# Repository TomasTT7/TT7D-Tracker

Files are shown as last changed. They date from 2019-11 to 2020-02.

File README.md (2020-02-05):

# TT7D-Tracker
This is the main repository for TT7D, a simple APRS / RTTY high altitude balloon tracker. It includes the board and schematic design files for Eagle, and the current firmware.

### Components:
- microcontroller: ATmega328P-AU
- GNSS module: u-blox MAX-M7 / MAX-M8 / GM10
- transmitter: Si4060 / Si4063 / Si4460 / Si4463
- TCXO: IT3205CE
- boost regulator: MCP1640B
- power supply: AAA battery / 2x solar cell
- GNSS antenna: JTI 1575AT43A0040 / wire

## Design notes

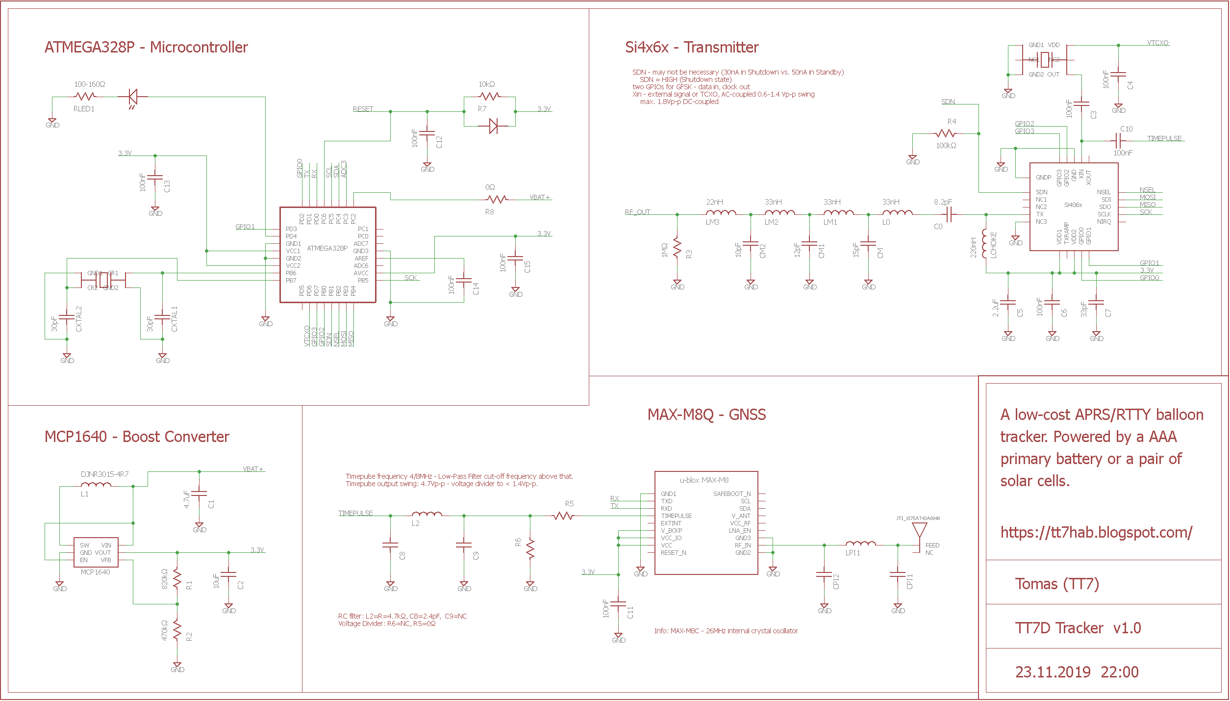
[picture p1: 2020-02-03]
Hardware/TT7D v1.0 schematic.png

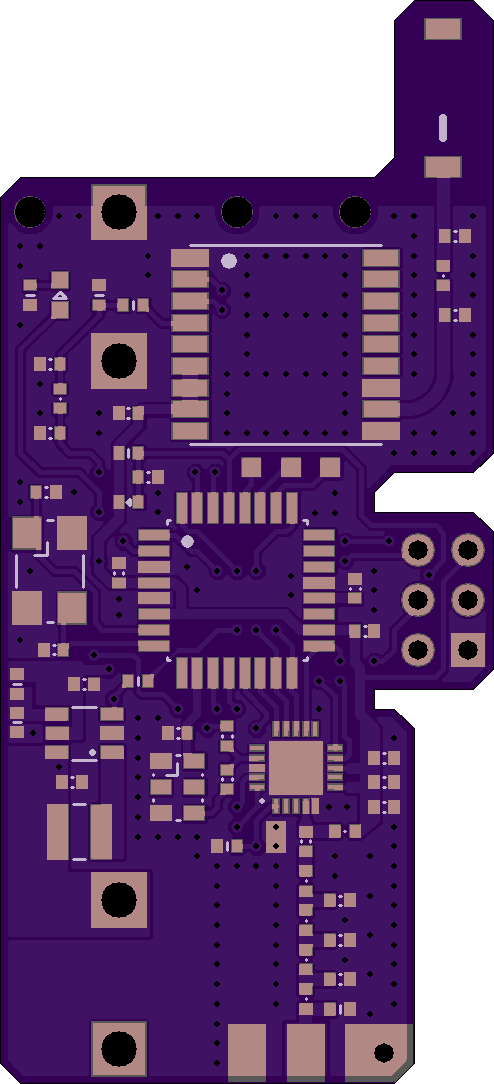
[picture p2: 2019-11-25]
Hardware/TT7D v1.0 top.png

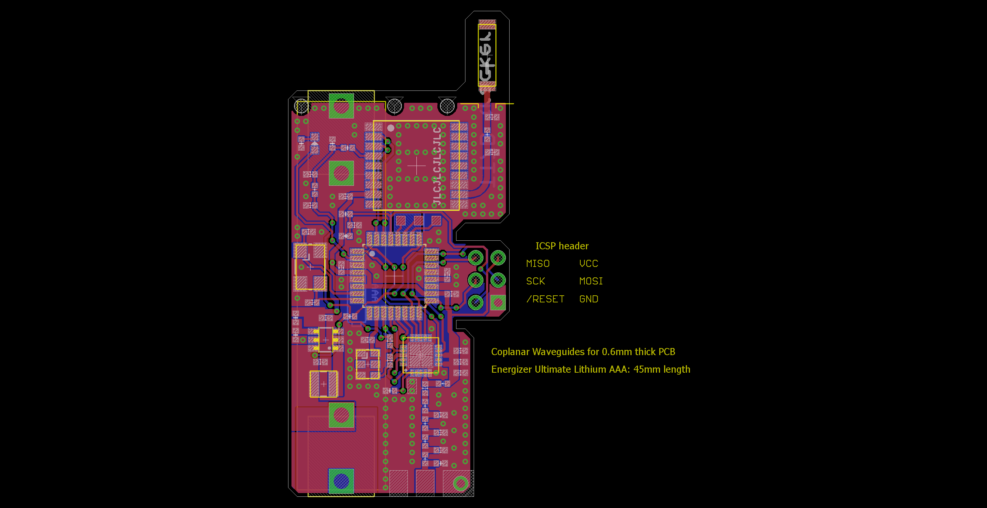
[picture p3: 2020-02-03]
Hardware/TT7D v1.0 board.png

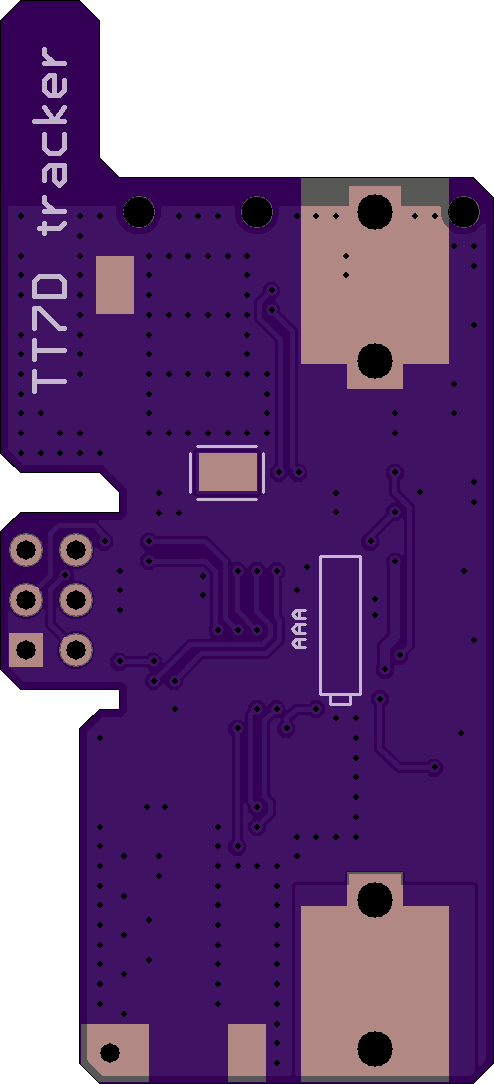
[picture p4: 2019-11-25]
Hardware/TT7D v1.0 bottom.png

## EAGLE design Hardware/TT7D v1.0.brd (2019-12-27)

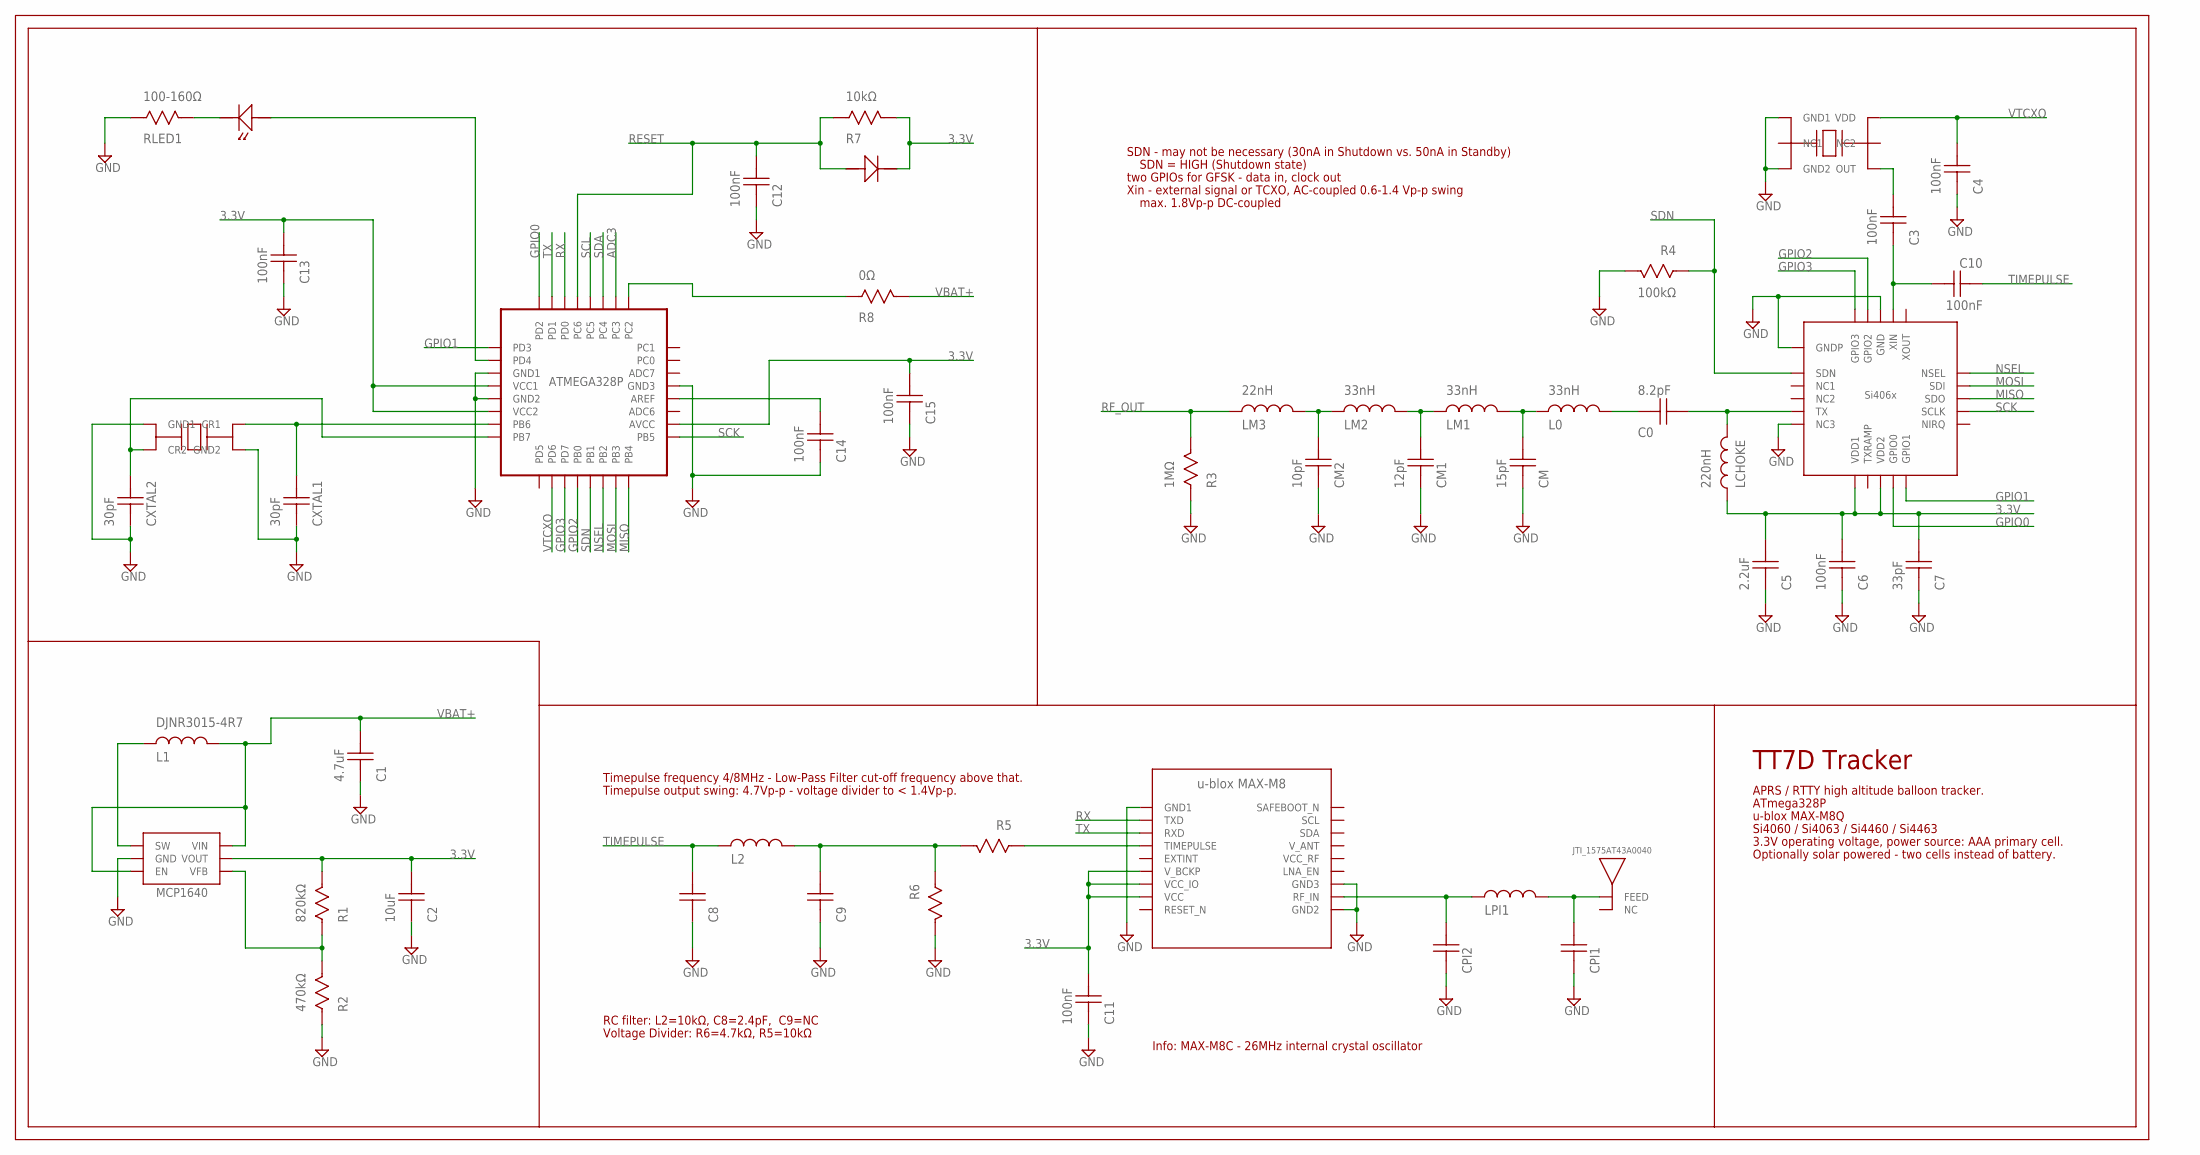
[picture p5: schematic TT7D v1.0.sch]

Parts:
ANT1: JTI_1575AT43A0040
C0: 8.2pF; CAP0402
C1: 4.7uF; CAP0402
C2: 10uF; CAP0402
C3, C4, C6, C10, C11, C12, C13, C14, C15: 100nF; CAP0402
C5: 2.2uF; CAP0402
C7: 33pF; CAP0402
C8, C9: CAP0402
CM: 15pF; CAP0402
CM1: 12pF; CAP0402
CM2: 10pF; CAP0402
CPI1, CPI2: CAP0402
CXTAL1, CXTAL2: 30pF; CAP0402
D1: DIODE0402
L0: 33nH; IND0402
L1: DJNR3015-4R7; DJNR3015
L2: IND0402
LCHOKE: 220nH; IND0402
LED1: LED0603
LM1, LM2: 33nH; IND0402
LM3: 22nH; IND0402
LPI1: IND0402
R1: 820kΩ; RES0402
R2: 470kΩ; RES0402
R3: 1MΩ; RES0402
R4: 100kΩ; RES0402
R5, R6: RES0402
R7: 10kΩ; RES0402
R8: 0Ω; RES0402
RLED1: 100-160Ω; RES0402
U1: ATMEGA328P-AU
U2: UBLOX_MAX-7C
U3: SI406X
U4: IT3205CE_TCXO_6P
U5: MCP1640
XTAL1: LFXTAL055663

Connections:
3.3V: C2.P$2, C5.P$2, C6.P$2, C7.P$2, C11.P$2, C13.P$2, C15.P$2, D1.CATHODE, LCHOKE.P$1, R1.P$2, R7.P$2, U1.AVCC, U1.VCC1, U1.VCC2, U2.VCC, U2.VCC_IO, U2.V_BCKP, U3.VDD1, U3.VDD2, U5.VOUT
ADC3: U1.PC3
GND: C1.P$1, C2.P$1, C4.P$1, C5.P$1, C6.P$1, C7.P$1, C8.P$1, C9.P$1, C11.P$1, C12.P$1, C13.P$1, C14.P$1, C15.P$1, CM.P$1, CM1.P$1, CM2.P$1, CPI1.P$1, CPI2.P$1, CXTAL1.P$1, CXTAL2.P$1, R2.P$1, R3.P$1, R4.P$2, R6.P$2, RLED1.P$1, U1.GND1, U1.GND2, U1.GND3, U2.GND1, U2.GND2, U2.GND3, U3.GND, U3.GNDP, U3.NC3, U4.GND1, U4.GND2, U5.GND, XTAL1.GND1, XTAL1.GND2
GPIO0: U1.PD2, U3.GPIO0
GPIO1: U1.PD3, U3.GPIO1
GPIO2: U1.PB0, U3.GPIO2
GPIO3: U1.PD7, U3.GPIO3
MISO: U1.PB4, U3.SDO
MOSI: U1.PB3, U3.SDI
unnamed: CXTAL2.P$2, U1.PB7, XTAL1.CRYSTAL2 (CR2)
unnamed: CXTAL1.P$2, U1.PB6, XTAL1.CRYSTAL1 (CR1)
unnamed: LED1.CATHODE, RLED1.P$2
unnamed: CPI2.P$2, LPI1.P$1, U2.RF_IN
unnamed: L1.P1, U5.SW
unnamed: CM.P$2, L0.P$1, LM1.P$2
unnamed: CM1.P$2, LM1.P$1, LM2.P$2
unnamed: R1.P$1, R2.P$2, U5.VFB
unnamed: CM2.P$2, LM2.P$1, LM3.P$2
unnamed: C0.P$1, L0.P$2
unnamed: C0.P$2, LCHOKE.P$2, U3.TX
unnamed: C14.P$2, U1.AREF
unnamed: C3.P$1, C10.P$2, U3.XIN
unnamed: C3.P$2, U4.OUT
unnamed: LED1.ANODE, U1.PD4
unnamed: R5.P$1, U2.TIMEPULSE
unnamed: C9.P$2, L2.P$2, R5.P$2, R6.P$1
unnamed: R8.P$1, U1.PC2
NSEL: U1.PB2, U3.NSEL
RESET: C12.P$2, D1.ANODE, R7.P$1, U1.PC6
RF_IN: ANT1.FEED, CPI1.P$2, LPI1.P$2
RF_OUT: LM3.P$1, R3.P$2
RX: U1.PD0, U2.TXD
SCK: U1.PB5, U3.SCLK
SCL: U1.PC5
SDA: U1.PC4
SDN: R4.P$1, U1.PB1, U3.SDN
TIMEPULSE: C8.P$2, C10.P$1, L2.P$1
TX: U1.PD1, U2.RXD
VBAT+: C1.P$2, L1.P2, R8.P$2, U5.EN, U5.VIN
VTCXO: C4.P$2, U1.PD6, U4.VDD

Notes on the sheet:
SDN - may not be necessary (30nA in Shutdown vs. 50nA in Standby)
SDN = HIGH (Shutdown state)
two GPIOs for GFSK - data in, clock out
Xin - external signal or TCXO, AC-coupled 0.6-1.4 Vp-p swing
max. 1.8Vp-p DC-coupled
Timepulse frequency 4/8MHz - Low-Pass Filter cut-off frequency above that.
Timepulse output swing: 4.7Vp-p - voltage divider to < 1.4Vp-p.
Info: MAX-M8C - 26MHz internal crystal oscillator
TT7D Tracker
APRS / RTTY high altitude balloon tracker.
ATmega328P
u-blox MAX-M8Q
Si4060 / Si4063 / Si4460 / Si4463
3.3V operating voltage, power source: AAA primary cell.
Optionally solar powered - two cells instead of battery.
RC filter: L2=10kΩ, C8=2.4pF, C9=NC
Voltage Divider: R6=4.7kΩ, R5=10kΩ

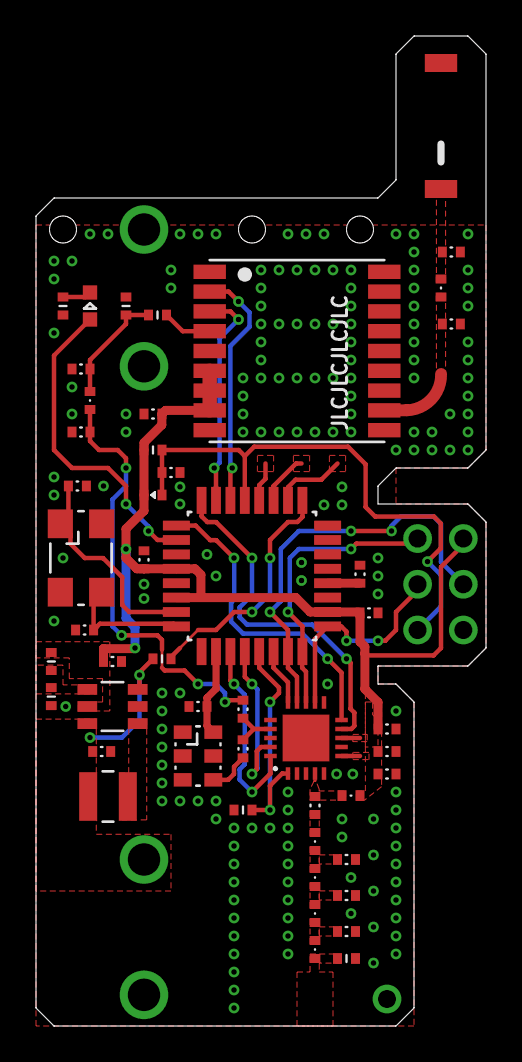
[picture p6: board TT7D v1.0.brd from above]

Board: 2 copper layers, 25.0 x 55.0 mm, 49 parts (0 on the bottom side), 37 nets.

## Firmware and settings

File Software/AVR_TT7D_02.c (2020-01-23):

/*
	Firmware for TT7D balloon tracker. Power saving low duty cycle version.
*/ 


// F_CPU defined in AVR/GNU C Compiler / Symbols


#include <avr/io.h>
#include <util/delay.h>
#include "AVR_ADC.h"
#include "AVR_APRS.h"
#include "AVR_GEOFENCE.h"
#include "AVR_RTTY.h"
#include "AVR_SERIAL.h"
#include "AVR_SI4X6X.h"
#include "AVR_SLEEP.h"
#include "AVR_SPI.h"
#include "AVR_TC.h"
#include "AVR_UART.h"
#include "AVR_UBLOX.h"
#include "AVR_WDT.h"


#define APRS																	// comment out to disable APRS
#define RTTY																	// comment out to disable RTTY

#define RTTY_FREQ		434300000												// [Hz] RTTY frequency

#define RTTY_CALL		"TT7D"
#define APRS_CALL		"OK7DMT"
#define APRS_SSID		15

#define RTTY_PWR		20
#define APRS_PWR		20

#define CYCLE_LENGTH	60000													// [ms] GNSS acquisition + RF transmissions + sleep cycle


// Main Function ---------------------------------------------------------------------------------
int main(void)
{
	/* WDT Initialization */
	WDT_enable_system_reset();													// 8 seconds, System Reset mode
	
	/* LED - Tracker Start */
    DDRD |= (1 << PORTD4);														// set PD4 to OUTPUT
	
	for(uint8_t i = 0; i < 3; i++)
	{
		PORTD |= (1 << PORTD4);													// set PD4 HIGH
        _delay_ms(20);
        PORTD &= ~(1 << PORTD4);												// set PD4 LOW
		_delay_ms(100);
	}
	
	/* GNSS Initialization */
	UART_init(9600);
	UBLOX_send_msg(dummyByte, 1);
	_delay_ms(500);																// GNSS module wake-up delay
	UBLOX_send_msg(timepulseOFF, 40);											// turn off timepulse
	UBLOX_send_msg(setNMEAoff, 28);												// turn off NMEA output
	UBLOX_send_msg(setDynamicModelAirborne, 44);								// Dynamic Model: Airborne (<1g)
	UBLOX_send_msg(saveConfiguration, 21);										// UBX-CFG-CFG: save current configuration
	UART_deinit();
	
	/* Si4063 Initialization */
	SPI_init_master();															// 4MHz SPI frequency
	SI4X6X_init(25000000, 1);													// TCXO (16369000 fails initialization)
	SI4X6X_deinit(1);
	SPI_deinit();
	
	WDT_timer_reset();															// Watchdog reset
	
	/* Telemetry Initialization */
	uint32_t APRS_sequence	= 0;
	uint32_t RTTY_sequence	= 0;
	
	uint16_t year			= 0;
	uint8_t month			= 0;
	uint8_t day				= 0;
	uint8_t hour			= 0;
	uint8_t min				= 0;
	uint8_t sec				= 0;
	uint8_t	valid			= 0;
	uint8_t fixType			= 0;
	uint8_t gnssFixOK		= 0;
	uint8_t psmState		= 0;
	uint8_t numSV			= 0;
	float lon				= 0.0;
	float lat				= 0.0;
	int32_t hMSL			= 0;
	uint32_t hAcc			= 0;
	uint32_t vAcc			= 0;
	uint16_t pDOP			= 0;
	
	uint16_t V_mV			= 0;
	uint16_t T_K			= 0;
	uint16_t T_Si_K			= 0;
	
	uint8_t reinit			= 0;
	uint32_t active_time	= 0;
	uint32_t timer			= 0;
	
	uint8_t GNSS_buffer[100];
	uint8_t packet[90];
	
	// Main Loop ---------------------------------------------------------------------------------
	while(1)
    {
		/* WatchDog Reset */
		WDT_timer_reset();														// Watchdog reset
		
		/* Elapsed Time Measurement */
		TC2_init(124, 4, 1);													// 1ms interrupt based counter
		
		/* GNSS Data Acquisition */
		uint8_t noposition = 0;
		uint8_t check = 0;
		
		UART_init(9600);
		UBLOX_send_msg(dummyByte, 1);
		_delay_ms(500);															// GNSS module wake-up delay
		
		UART_flush();
		UBLOX_send_msg(requestNAV5, 8);											// poll UBX-CFG-NAV5
		
		check = UBLOX_receive_msg(GNSS_buffer, 44, 0);							// UBX-CFG-NAV5: 44 bytes
		
		if(check)
		{
			uint8_t model = GNSS_buffer[8];										// check Dynamic Model
			
			if(model != 6) UBLOX_send_msg(setDynamicModelAirborne, 44);			// Dynamic Model: Airborne (<1g)
		}else{
			UBLOX_send_msg(setDynamicModelAirborne, 44);						// Dynamic Model: Airborne (<1g)
		}
		
		_delay_ms(100);															// in case UBX-ACK-ACK is sent
		
		uint8_t valid_time = 0;
		uint8_t attempts = 0;
		
		while(1)
		{
			/* WatchDog Reset */
			WDT_timer_reset();													// Watchdog reset
			
			attempts++;
		
			UART_flush();
			UBLOX_send_msg(requestPVT, 8);										// poll UBX-NAV-PVT
		
			check = UBLOX_receive_msg(GNSS_buffer, 92, 0);						// UBX-NAV-PVT: MAX-M8 100 bytes, Biwin GM10: 92 bytes
		
			if(check)
			{
				UBLOX_parse_0107(GNSS_buffer, &year, &month, &day, &hour, &min, &sec, &valid, &fixType,
								&gnssFixOK, &psmState, &numSV, &lon, &lat, &hMSL, &hAcc, &vAcc, &pDOP);
			
				if((valid & 0x04) == 0x04 || (valid & 0x03) == 0x03) valid_time = 1;
				else valid_time = 0;
			
				if(gnssFixOK && valid_time && numSV >= 5)						// valid fix, time and date and minimum number of satellites condition
				{
					noposition = 0;
					break;
				}
			}
			
			if(attempts > 37)													// limit acquisition to 37s - ephemeris cycle 18-36s
			{
				noposition = 1;
				break;
			}
		}
		
		if(noposition)
		{
			if(!valid_time)
			{
				year = 0;
				month = 0;
				day = 0;
				hour = 0;
				min = 0;
				sec = 0;
				
				reinit++;														// increase counter of failed fix acquisitions in row
			}
			
			valid = 0;
			fixType = 0;
			gnssFixOK = 0;
			psmState = 0;
			numSV = 0;
			lon = 0.0;
			lat = 0.0;
			hMSL = 0;
			hAcc = 0;
			vAcc = 0;
			pDOP = 0;
		}
		else
		{
			reinit = 0;															// reset counter of failed fix acquisitions in row
		}
		
		UBLOX_send_msg(saveConfiguration, 21);									// UBX-CFG-CFG: save current configuration
		UBLOX_send_msg(setBackupMode, 16);										// command GNSS module to software backup mode 
		UART_deinit();
		
		/* ADC */
		ADC_init_AVCC(2);
		uint16_t V_raw = ADC_sample_channel(10);
		ADC_deinit();
		
		ADC_init_temperature();
		uint16_t T_raw = ADC_sample_channel(10);
		ADC_deinit();
        
		V_mV = ADC_calculate_voltage(V_raw, 3380);								// [mV]
		T_K = ADC_calculate_temperature(T_raw, 0, 1);							// [?]
		
		/* Si4063 Temperature */
		SPI_init_master();														// 4MHz SPI frequency
		SI4X6X_init(25000000, 1);												// TCXO (16369000 fails initialization)
		
		uint16_t T_Si_raw = SI4X6X_get_temperature();
		T_Si_K = (uint32_t)T_Si_raw * 8990 / 4096 - 200;						// [0.1K]
		
		SI4X6X_deinit(1);
		SPI_deinit();
		
		/* WatchDog Reset */
		WDT_timer_reset();														// Watchdog reset
		
		/* Elapsed Time Measurement */
		timer = TC2_elapsed_time(0);
		active_time = timer;
		
	#ifdef APRS
		/* Sequence Counter */
		APRS_sequence++;
		
		/* APRS Packet */
		uint8_t aprs_bitstream[90] = {0};
		
		uint8_t B = APRS_packet(packet, (uint8_t *)APRS_CALL, APRS_SSID, lat, lon, (uint16_t)hMSL,
								APRS_sequence, numSV, V_mV, T_Si_K, active_time / 100, noposition);
		uint16_t b = APRS_bitstream(packet, B, aprs_bitstream);
		
		/* GeoFenced Frequency - APRS */
		uint32_t tx_frequency = GEOFENCE_frequency(lat, lon);					// decide on frequency based on GPS position
		
		/* APRS Transmission */
		if(tx_frequency > 144000000 && tx_frequency < 146000000)				// no transmission if tx_frequency equals 0
		{
			/* Si4063 Setup */
			SPI_init_master();													// 4MHz SPI frequency
			SI4X6X_init(25000000, 1);											// TCXO (16369000 fails initialization)
			SI4X6X_set_PA_mode(2, 0);											// Si4463/64: higher maximum power, Switching-Amplifier Mode
			SI4X6X_set_power_level(APRS_PWR);									// 
			
			/* LED - APRS Transmission */
			PORTD |= (1 << PORTD4);												// set PD4 HIGH
			
			SI4X6X_tx_GFSK_aprs(aprs_bitstream, b, tx_frequency, 16369000, 0);
			
			PORTD &= ~(1 << PORTD4);											// set PD4 LOW
			
			SI4X6X_deinit(1);
			SPI_deinit();
		}
	#endif
		
		/* WatchDog Reset */
		WDT_timer_reset();														// Watchdog reset
		
	#ifdef RTTY
		/* Sequence Counter */
		RTTY_sequence++;
		
		/* RTTY Packet */
		uint8_t n = RTTY_packet(packet, (uint8_t *)RTTY_CALL, RTTY_sequence, hour, min, sec, year, month, day,
								lat, lon, hMSL, numSV, V_mV, T_Si_K, active_time / 100);
		
		/* Si4063 Setup */
		SPI_init_master();														// 4MHz SPI frequency
		SI4X6X_init(25000000, 1);												// TCXO (16369000 fails initialization)
		SI4X6X_set_PA_mode(2, 0);												// Si4463/64: higher maximum power, Switching-Amplifier Mode
		SI4X6X_set_power_level(RTTY_PWR);										// 
		
		/* CW Blips */
		SI4X6X_tx_CW_blips(5, 500, RTTY_FREQ, 16369000, 0);
		
		/* RTTY Transmission */
		SI4X6X_tx_FSK_rtty(packet, n, 100, RTTY_FREQ, 16369000, 29, 29);		// 100 baud (~8s transmission)
		
		SI4X6X_deinit(1);
		SPI_deinit();
		
		/* LED - RTTY Transmission */
		PORTD |= (1 << PORTD4);													// set PD4 HIGH
        _delay_ms(20);
        PORTD &= ~(1 << PORTD4);												// set PD4 LOW
	#endif
		
		/* Elapsed Time Measurement */
		timer = TC2_elapsed_time(1);
		TC2_deinit();
		
		/* Forced Reset Check */
		if(reinit >= 5)
		{
			WDT_force_system_reset();											// enables 16ms WatchDog
			_delay_ms(100);
		}
		
		/* Sleep */
		uint32_t sleep = (CYCLE_LENGTH - timer) / 4000;
		
		for(uint8_t i = 0; i < sleep; i++)
		{
			WDT_enable_system_reset_interrupt();								// 4 seconds
			SLEEP_enable(2);													// sleep for 4 seconds
		}
		
		/* WDT - Restore */
		WDT_enable_system_reset();												// 8 seconds, System Reset mode
	}
}

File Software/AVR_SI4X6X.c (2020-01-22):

/*
	Si4x6x <-> ATmega328P
		NSEL	PB2 (SS)
		SDI		PB3 (MOSI)
		SDO		PB4 (MISO)
		SCLK	PB5 (SCK)
		
		GPIO0	PD2 (INT0 - external interrupt)		CTS (output) - HIGH when able to receive
		GPIO1	PD3 (INT1 - external interrupt)		TX_DATA_CLK (output) - for use in TX Direct Synchronous Mode
		GPIO2	PB0									INPUT (input) - TXDATA for TX Direct Mode
		GPIO3	PD7									TRISTATE - input and output drivers disabled
		
		SDN		PB1 (LOW - IC active, HIGH - IC shutdown)
		VTCXO	PD6 (if used)
	
	Si4x6x Reference (Xin pin)
		Timepulse	needs setting up via the GNSS module
		TCXO		needs power via PD6
	
	A single high precision local oscillator (LO) is used for transmit mode. The LO is generated by an integrated VCO
	and ΔΣ Fractional-N PLL synthesizer. The synthesizer is designed to support configurable data rates from 100 bps
	to 1 Mbps.
	
	Frequency Bands		Resolution		Modulation Range
	142-175MHz			4.7Hz			250kHz
	283–350MHz			9.5Hz			500kHz
	420–525MHz			14.3Hz			750kHz
	850–1050MHz			28.6Hz			1.5MHz
	
	The transmit FSK data is modulated directly into the ΔΣ	data stream and can be shaped by a Gaussian low-pass filter
	to reduce unwanted spectral content.
*/


#include "AVR_SI4X6X.h"


volatile uint8_t gfsk_toggle = 0;


/*
	Si4x6x Initialization
		-drive SDN HIGH for a minimum of 10us
		-drive SDN LOW again
		-Power on Reset (POR) requires 10ms to settle the circuit
		-POWER_UP command is required to initialize the radio
	
	TCXO
		0	Timepulse reference signal to Si4x6x
		1	TCXO reference signal to Si4x6x
		
	XO_FREQ
		Setting XO_FREQ in POWER_UP command to the TCXO's frequency of 16,369,000Hz (out of specs) fails the initialization.
		Leaving it at default 30,000,000Hz or setting it to the minimum of 25,000,000Hz proceeds the initialization fine.
*/
void SI4X6X_init(uint32_t ref_freq, uint8_t tcxo)
{
	/* Assumes SPI interface already initialized */
	
	/* The XO capacitor bank should be set to 0 whenever an external drive is used on the XIN pin. */
	uint8_t rx_buffer[16];
	
	SPI_assert_SS();
	SPI_master_transmit(0x11);											// SET_PROPERTY (CMD)
	SPI_master_transmit(0x00);											// GLOBAL (group)
	SPI_master_transmit(0x01);											// 1 (num_props)
	SPI_master_transmit(0x00);											// GLOBAL_XO_TUNE (start_prop)
	SPI_master_transmit(0x00);											// FASTEST_FREQUENCY (Lowest capacitance)
	SPI_deassert_SS();
	SI4X6X_rx_CTS(rx_buffer, 1);
	
	/* Assumes Timepulse to Xin pin already enabled. */
	if(tcxo)
	{
		DDRD |= (1 << PORTD6);											// set PD6 to OUTPUT
		PORTD |= (1 << PORTD6);											// set PD6 HIGH
	}
	
	/* ATmega328P Pins Setup */
	DDRD &= ~((1 << PORTD2) | (1 << PORTD3) | (1 << PORTD7));			// set PD2, PD3 and PD7 to INPUT
	DDRB |= (1 << PORTB1) | (1 << PORTB0);								// set PB0 and PB1 to OUTPUT
	PORTB &= ~(1 << PORTB0);											// set PB0 (GPIO2 - TXDATA) LOW
	
	/* POWER_UP Sequence */
	PORTB |= (1 << PORTB1);												// set PB1 (SDN) HIGH
	_delay_ms(1);
	PORTB &= ~(1 << PORTB1);											// set PB1 (SDN) LOW
	_delay_ms(10);														// wait for POR to finish
	
	SPI_assert_SS();
	SPI_master_transmit(0x02);											// POWER_UP - 15ms
	SPI_master_transmit(0x01);
	SPI_master_transmit(0x01);											// 0x00 - XTAL, 0x01 - TCXO
	SPI_master_transmit(ref_freq / 16777216);
	SPI_master_transmit(ref_freq % 16777216 / 65536);
	SPI_master_transmit(ref_freq % 16777216 % 65536 / 256);
	SPI_master_transmit(ref_freq % 16777216 % 65536 % 256);
	SPI_deassert_SS();
	SI4X6X_rx_CTS(rx_buffer, 1);
	
	SPI_assert_SS();
	SPI_master_transmit(0x20);											// GET_INT_STATUS (clear interrupts)
	SPI_deassert_SS();
	SI4X6X_rx_CTS(rx_buffer, 9);
	
	/* Si4x6x Pins Setup */
	SI4X6X_setup_pins(8, 16, 4, 1, 0, 0);
}


/*
	Leaves the IC in Standby or Sleep state (low consumption).
*/
void SI4X6X_deinit(uint8_t tcxo)
{
	SI4X6X_change_state(1);												// SLEEP/STANDBY
	
	/* ATmega328P Pins Deinit */
	PORTB &= ~(1 << PORTB0);											// set PB0 (GPIO2 - TXDATA) LOW
	DDRB &= ~(1 << PORTB0);												// set PB0 to INPUT
	
	/* Deinit SDN */
	PORTB &= ~(1 << PORTB1);											// set PB1 (SDN) LOW
	DDRB &= ~(1 << PORTB1);												// set PB1 to INPUT
	
	/* TCXO Reference */
	if(tcxo)
	{
		PORTD &= ~(1 << PORTD6);										// set PD6 LOW
		DDRD &= ~(1 << PORTD6);											// set PD6 to INPUT
	}
}


/*
	CLEAR TO SEND (CTS)
		Checking CTS is used to make sure the internal MCU has executed the command and prepared the data to be output over the SDO pin.
		
	Function checks CTS by issuing READ_CMD_BUFF then receives the data response.
*/
void SI4X6X_rx_CTS(uint8_t * rx_buffer, uint8_t len)
{
	uint8_t _cts;
	uint32_t timeout = 15000;
	
	while(timeout--)
	{
		SPI_assert_SS();
		
		SPI_master_transmit(0x44);										// READ_CMD_BUFF
		_cts = SPI_master_transmit(0x00);

		if(_cts == 0xFF) break;
		SPI_deassert_SS();
	}
	
	rx_buffer[0] = _cts;
	
	for(uint8_t i = 1; i < len; i++)
	{
		rx_buffer[i] = SPI_master_transmit(0x00);
	}
	
	SPI_deassert_SS();
}


/*
	CLEAR TO SEND (CTS)
		Checking CTS is used to make sure the internal MCU has executed the command and prepared the data to be output over the SDO pin.
	
	Function waits for the CTS signal on a GPIO0 pin.
*/
void SI4X6X_check_CTS(void)
{
	/* Assumes GPIO0 already configured to output CTS signal */
	
	uint32_t timeout = 15000;
	
	while(timeout--)
	{
		if(PIND & (1 << PORTD2)) break;
	}
}


/*
	TYPICAL SETTINGS
		GPIO0			8		disable pull-up, Clear To Send signal output
		GPIO1			16		disable pull-up, TX Data Clock signal output
		GPIO2			4		disable pull-up, TXDATA input for TX Direct Mode
		GPIO3			1		disable pull-up, Input and output drivers disabled
		NIRQ			0		disable pull-up, behavior of this pin is not modified
		SDO				0		disable pull-up, behavior of this pin is not modified
		GEN_CONFIG		0		GPIOs configured as outputs will have the highest drive strength
*/
void SI4X6X_setup_pins(uint8_t gpio0, uint8_t gpio1, uint8_t gpio2, uint8_t gpio3, uint8_t nirq, uint8_t sdo)
{
	uint8_t rx_buffer[16];
	
	SPI_assert_SS();
	SPI_master_transmit(0x13);											// GPIO_PIN_CFG
	SPI_master_transmit(gpio0);											// GPIO0
	SPI_master_transmit(gpio1);											// GPIO1
	SPI_master_transmit(gpio2);											// GPIO2
	SPI_master_transmit(gpio3);											// GPIO3
	SPI_master_transmit(nirq);											// NIRQ
	SPI_master_transmit(sdo);											// SDO
	SPI_master_transmit(0x00);											// Drive Strength
	SPI_deassert_SS();
	SI4X6X_rx_CTS(rx_buffer, 8);
}
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
